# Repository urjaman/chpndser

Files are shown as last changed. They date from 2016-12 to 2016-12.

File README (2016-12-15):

CH340g-based debug serial dongle for the pandora ext port
----------------------------------------------------------

Parts list:
- usb mini b connector
- ch340g
- NX3008NBKW,115 SOT-323 n-ch mosfet
- 12Mhz HC-49 SMD crystal
- 2* 22pF 0603 cap
- 2* 0.1u 0603 cap
- 4* 4k7 0603 resistors
- pandora ext port connector

The PCB is shared at oshpark:
https://oshpark.com/shared_projects/jlOmwnKj
remember to pick the 0.8mm service

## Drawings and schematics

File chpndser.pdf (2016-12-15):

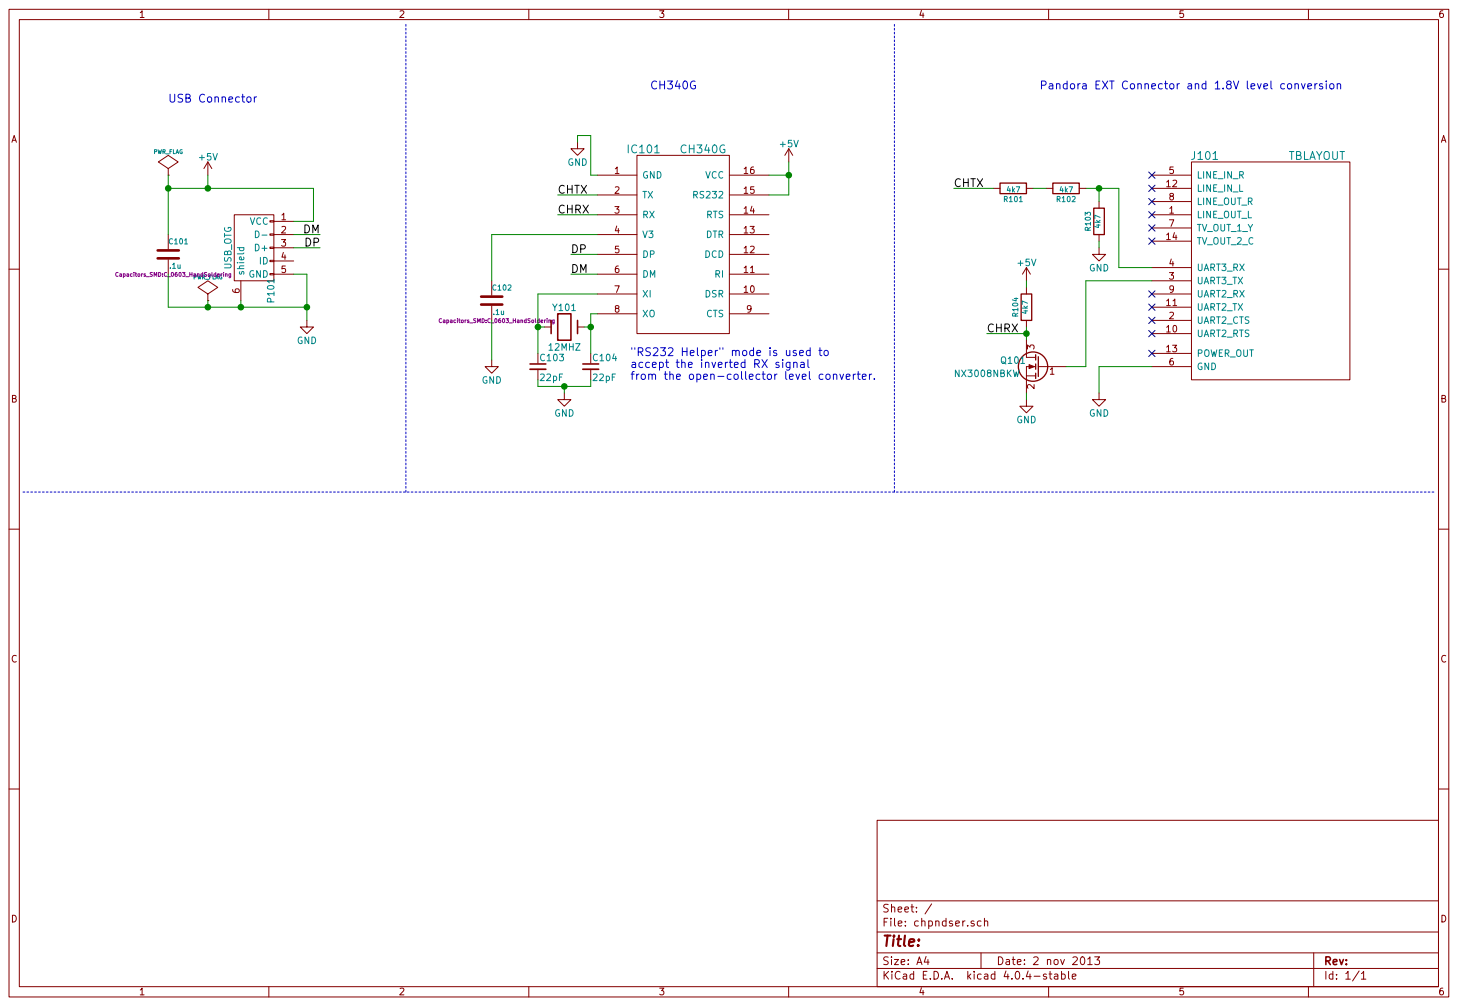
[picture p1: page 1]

"RS232 Helper" mode is used to
accept the inverted RX signal
from the open-collector level converter.

File: chpndser.sch Sheet: /
Id: 1/1 Title:

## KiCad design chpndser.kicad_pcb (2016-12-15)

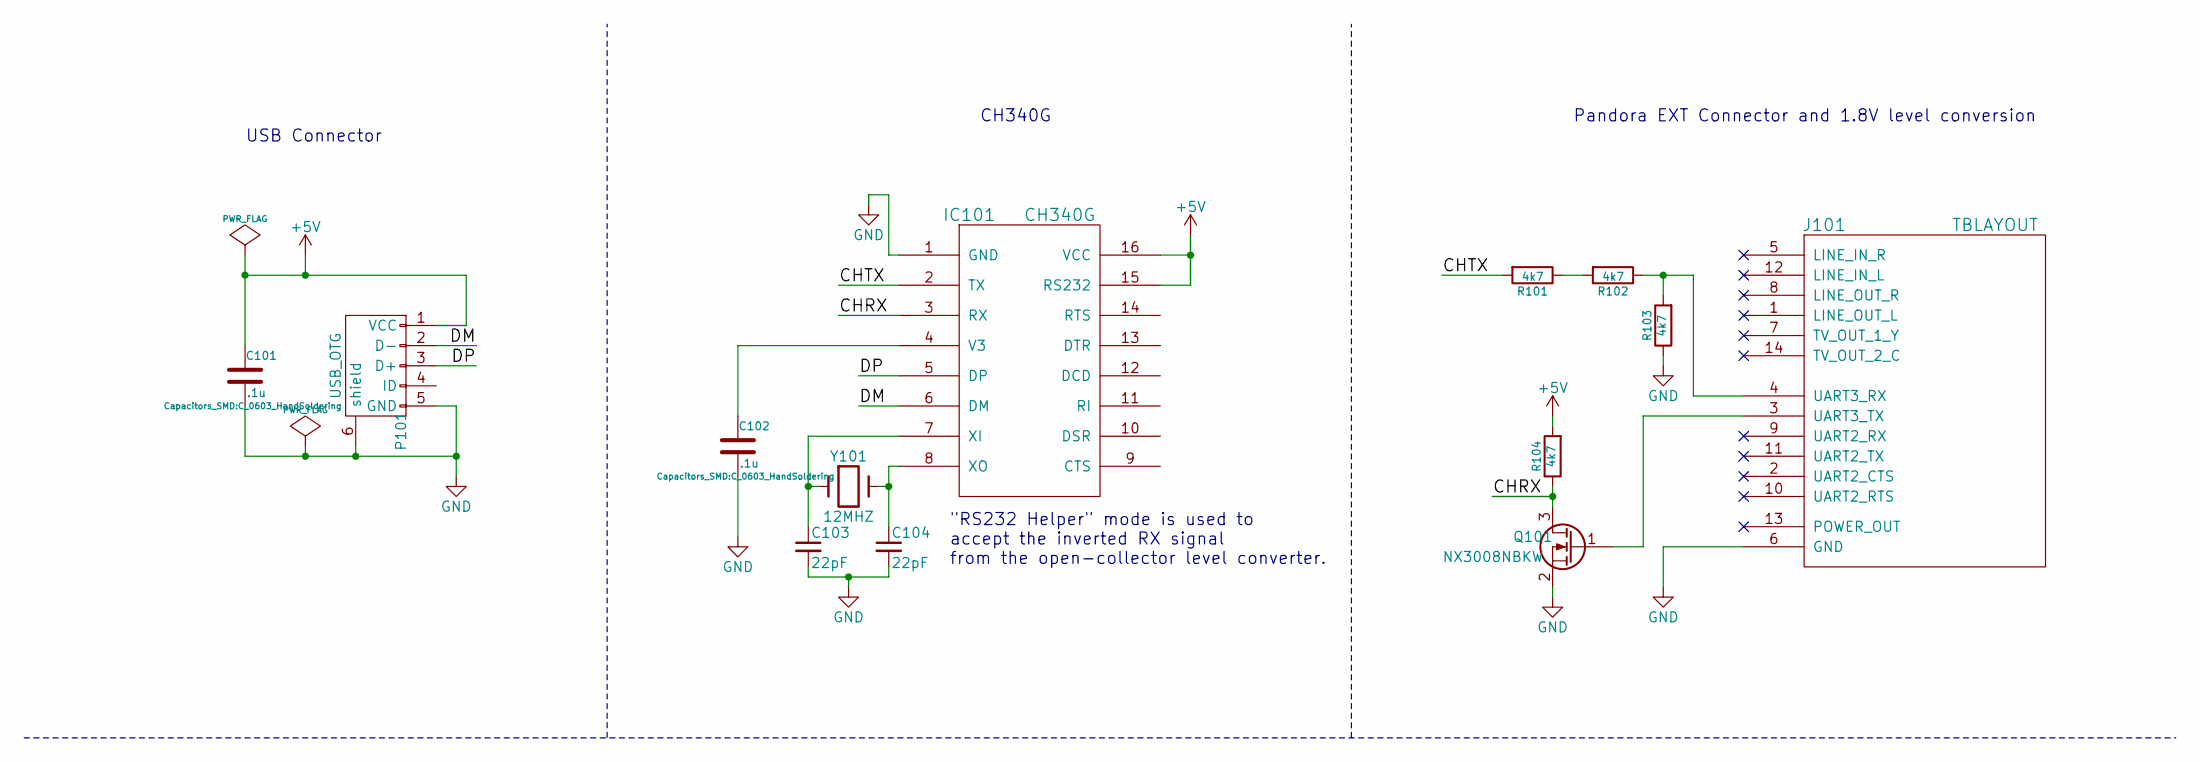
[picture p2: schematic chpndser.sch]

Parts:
C101, C102: .1u; C_0603_HandSoldering
C103, C104: 22pF; C_0603_HandSoldering
IC101: CH340G; SOIC-16_3.9x9.9mm_Pitch1.27mm
J101: TBLAYOUT; TBLAYOUT-ASTRON
P101: USB_OTG; USB_Mini-B
Q101: NX3008NBKW; SOT-323
R101, R102, R103, R104: 4k7; R_0603_HandSoldering
Y101: 12MHZ; Crystal_HC49-SD_SMD

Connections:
+5V: C101.1, IC101.15 (RS232), IC101.16 (VCC), P101.1 (VCC), R104.2
/CHRX: IC101.3 (RX), Q101.3 (D), R104.1
/CHTX: IC101.2 (TX), R101.2
/DM: IC101.6 (DM), P101.2 (D-)
/DP: IC101.5 (DP), P101.3 (D+)
GND: C101.2, C102.2, C103.2, C104.2, IC101.1 (GND), J101.6 (GND), P101.5 (GND), P101.6 (shield), Q101.2 (S), R103.1
unnamed: C102.1, IC101.4 (V3)
unnamed: C103.1, IC101.7 (XI), Y101.1
unnamed: C104.1, IC101.8 (XO), Y101.2
unnamed: J101.3 (UART3_TX), Q101.1 (G)
unnamed: J101.4 (UART3_RX), R102.1, R103.2
unnamed: R101.1, R102.2

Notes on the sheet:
USB Connector
CH340G
Pandora EXT Connector and 1.8V level conversion
"RS232 Helper" mode is used to accept the inverted RX signal from the open-collector level converter.

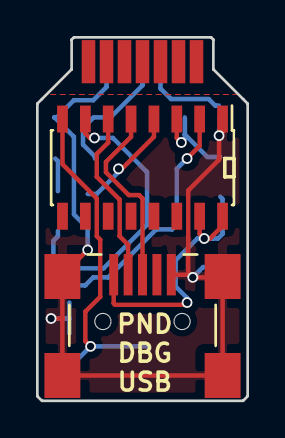
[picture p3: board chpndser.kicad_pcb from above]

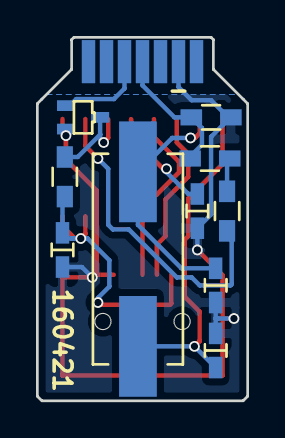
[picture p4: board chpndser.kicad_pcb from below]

Board: 2 copper layers, 11.7 x 20.2 mm, 13 parts (10 on the bottom side), 12 nets.

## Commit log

2016-03-15 First stuff
    [chpndser.kicad_pcb, chpndser.sch]
2016-03-16 better version
    [chpndser.kicad_pcb, chpndser.sch]
2016-12-15 First public release version
    [chpndser-B.Cu.gbr, chpndser-B.Mask.gbr, chpndser-B.SilkS.gbr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]
2016-12-15 add a note about the 0.8mm thing
